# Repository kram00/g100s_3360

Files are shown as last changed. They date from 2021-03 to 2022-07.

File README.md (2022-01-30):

# g100s_3360

original code from https://gist.github.com/qsxcv/53c52e2bf6ed1f0b6c2a8a0d21219476 and https://www.overclock.net/threads/reverse-engineering-3366.1561041/post-28068670

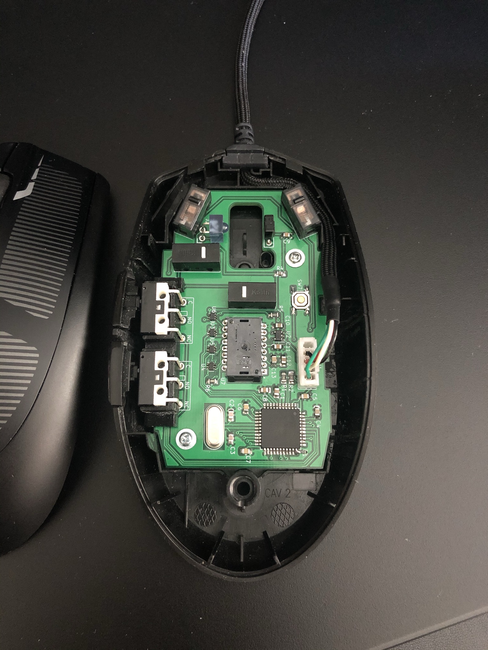
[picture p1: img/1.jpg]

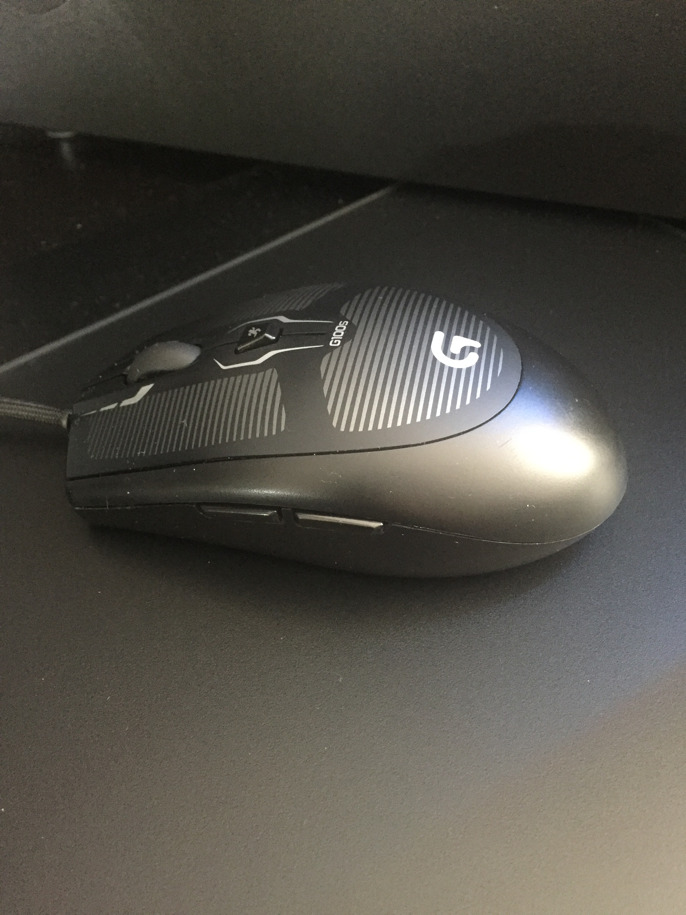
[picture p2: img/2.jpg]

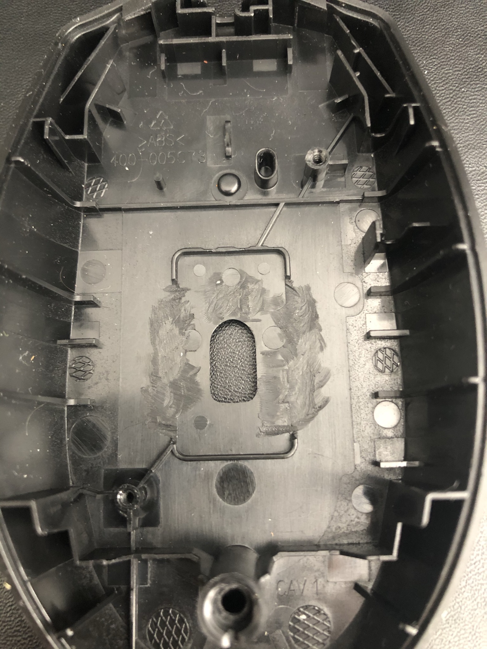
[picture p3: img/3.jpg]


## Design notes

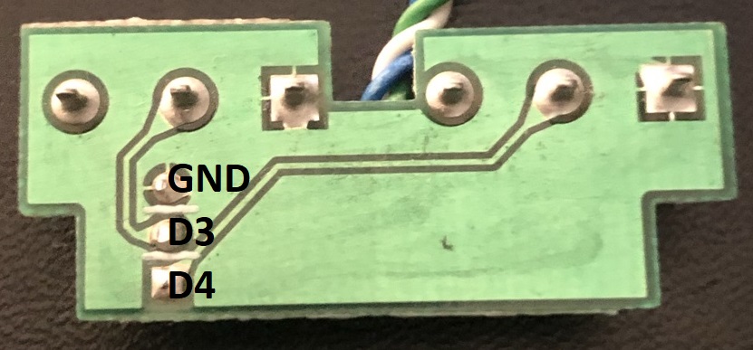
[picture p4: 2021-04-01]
img/sidebuttons.jpg

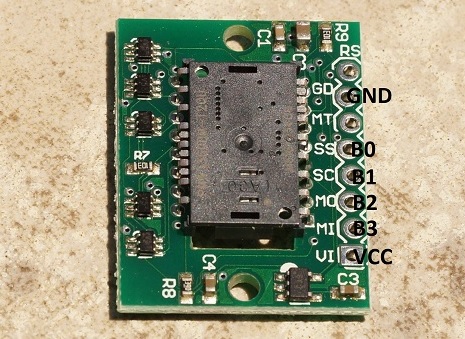
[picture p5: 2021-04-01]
img/3360_teensy.jpg

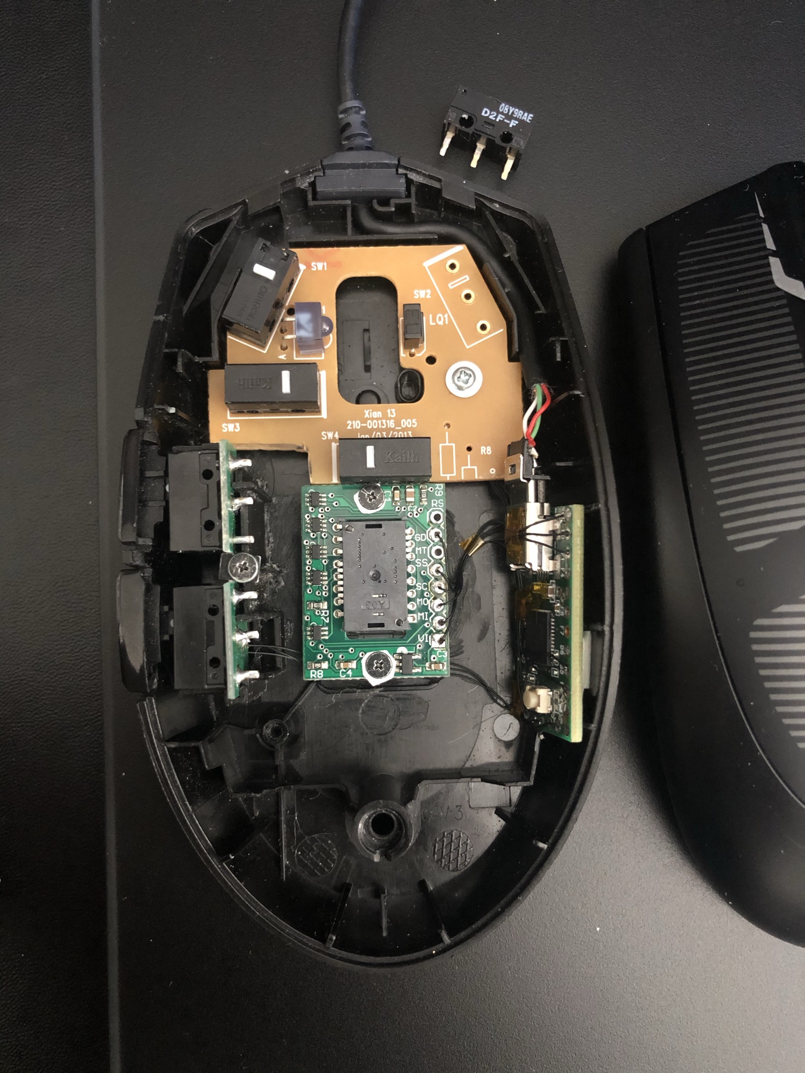
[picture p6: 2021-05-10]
img/g100s_3360_1.jpg

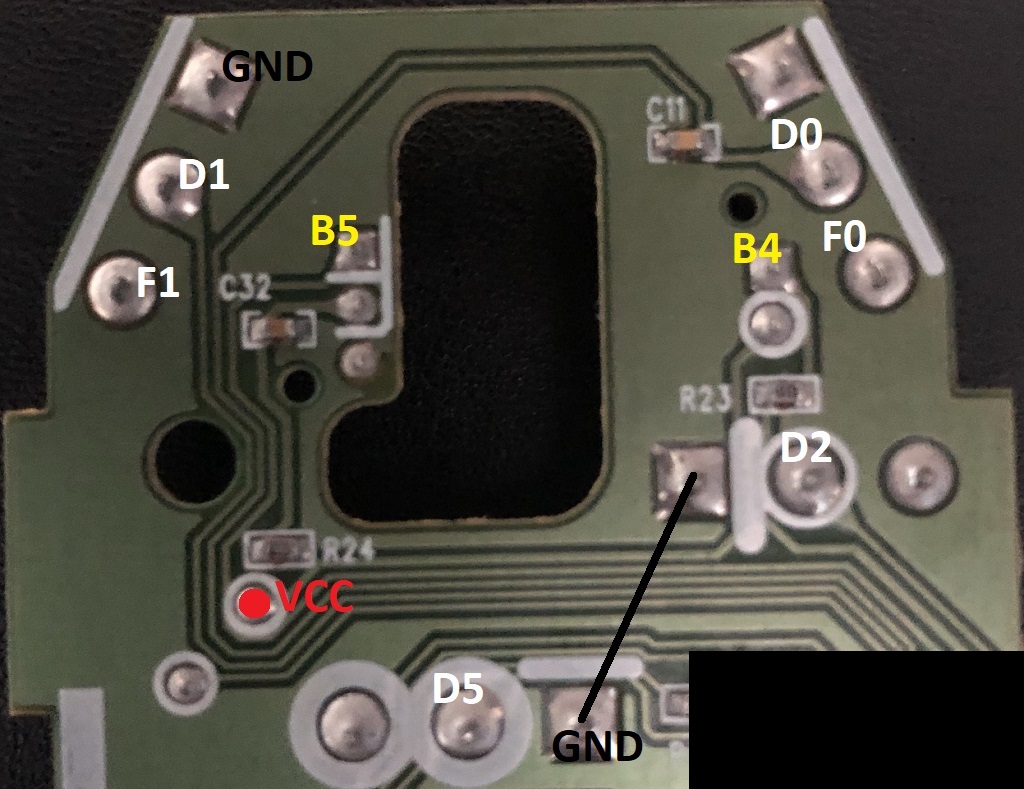
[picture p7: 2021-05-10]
img/buttons_scroll.jpg

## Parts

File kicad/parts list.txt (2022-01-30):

order on lcsc:

Samsung Electro-Mechanics CL21C220JBANNNC 22pF	2x	C1804
YAGEO CC0805KRX7R9BB104 100nF			5x	C49678
Samsung Electro-Mechanics CL21A475KAQNNNE 4.7uF	2x	C1779
Samsung Electro-Mechanics CL21B105KBFNNNE 1uF	4x	C28323
Uniroyal Elec 0805W8F1002T5E 10kΩ		1x	C17414
Uniroyal Elec 0805W8F220JT5E 22Ω		2x	C17561
Uniroyal Elec 0805W8F1500T5E 150Ω		1x	C17471
Uniroyal Elec 0805W8F100JT5E 10Ω		1x	C17415
Uniroyal Elec 0805W8F1001T5E 1kΩ		1x	C17513

Uniroyal Elec 0805W8F390JT5E 39Ω		1x	C17659
Microchip Tech ATMEGA32U4-AU C44854		1x	C44854
Texas Instruments SN74LVC1T45DCKR		4x	C9382
CITIZEN HC-49/U-S16000000ABJB			1x	C326538
								
-------------------------------------------------------------------------
not available on lcsc:

Texas Instruments TLV70019DDCR			1x	https://aliexpress.com/item/1005003054170479.html
PMW3360DM-T2QU + LM19-LSI			1x	https://aliexpress.com/item/32834829893.html
micro switch 4mmx4mmx1.5mm			1x	https://aliexpress.com/item/32915426986.html
ir led and detector				1x	recycle from g100s pcb or https://aliexpress.com/item/4000184464797.html
jst-ph 5pin					1x	recycle from g100s pcb or https://aliexpress.com/item/32400992588.html
								
-------------------------------------------------------------------------

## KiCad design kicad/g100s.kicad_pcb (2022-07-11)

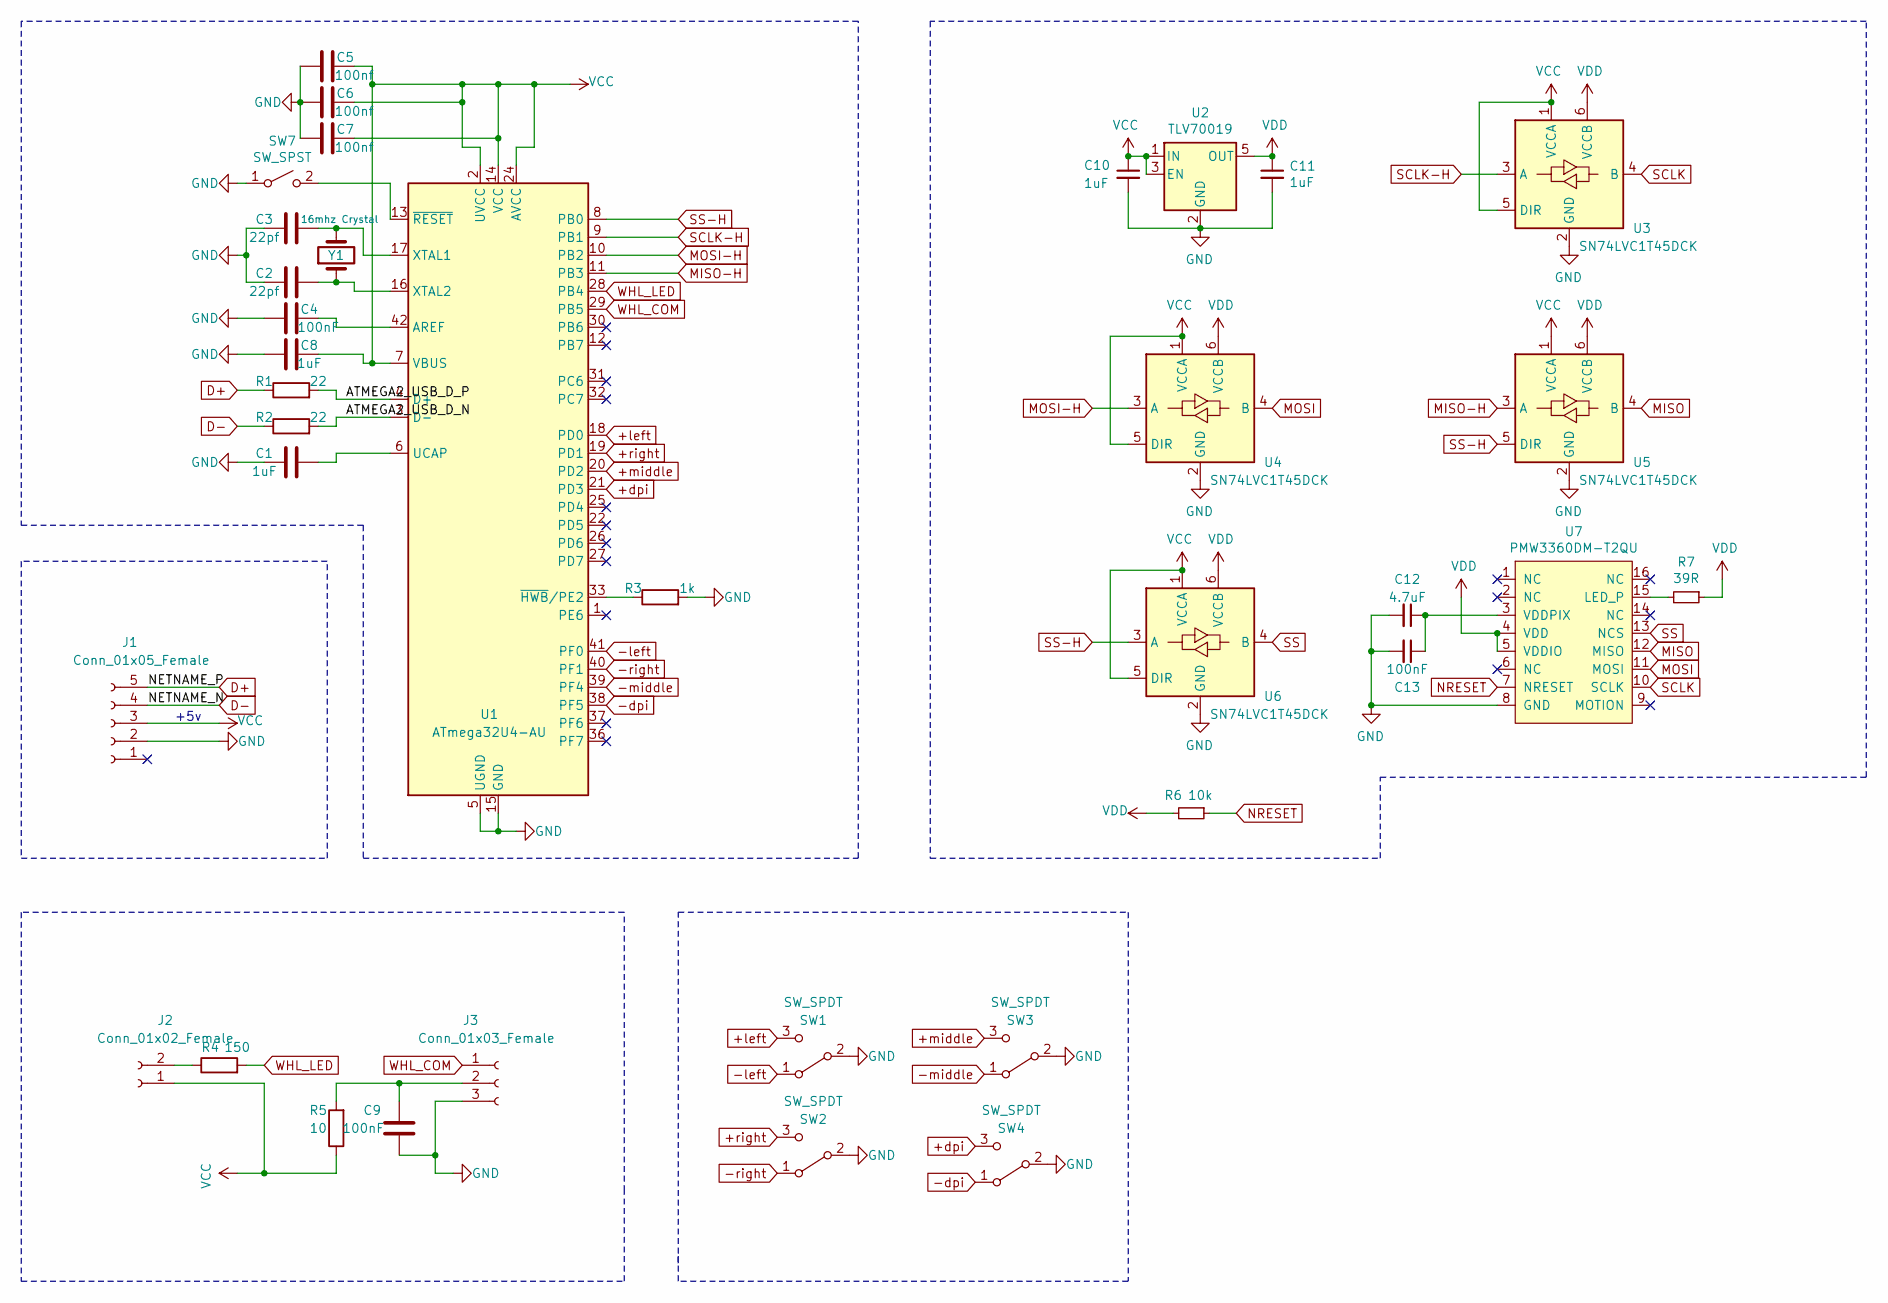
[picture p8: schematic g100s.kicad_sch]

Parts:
C1, C8, C10, C11: 1uF; C_0805_2012Metric_Pad1.18x1.45mm_HandSolder
C2, C3: 22pf; C_0805_2012Metric_Pad1.18x1.45mm_HandSolder
C4, C9, C13: 100nF; C_0805_2012Metric_Pad1.18x1.45mm_HandSolder
C5, C6, C7: 100nf; C_0805_2012Metric_Pad1.18x1.45mm_HandSolder
C12: 4.7uF; C_0805_2012Metric_Pad1.18x1.45mm_HandSolder
J1: Conn_01x05_Female; JST_PH_B5B-PH-K_1x05_P2.00mm_Vertical
J2: Conn_01x02_Female; PinSocket_1x02_P2.54mm_Vertical
J3: Conn_01x03_Female; PinSocket_1x03_P2.54mm_Vertical
R1, R2: 22; R_0805_2012Metric_Pad1.20x1.40mm_HandSolder
R3: 1k; R_0805_2012Metric_Pad1.20x1.40mm_HandSolder
R4: 150; R_0805_2012Metric_Pad1.20x1.40mm_HandSolder
R5: 10; R_0805_2012Metric_Pad1.20x1.40mm_HandSolder
R6: 10k; C_0805_2012Metric_Pad1.18x1.45mm_HandSolder
R7: 39R; C_0805_2012Metric_Pad1.18x1.45mm_HandSolder
SW1, SW2, SW3, SW4: SW_SPDT; Microswitch_SPDT_D2F
SW7: SW_SPST; SW_SPST_TL3342
U1: ATmega32U4-AU; TQFP-44_10x10mm_P0.8mm
U2: TLV70019; SOT-23-5
U3, U4, U5, U6: SN74LVC1T45DCK; SOT-363_SC-70-6
U7: PMW3360DM-T2QU
Y1: 16mhz Crystal; Crystal_HC49-U_Vertical

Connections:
+dpi: SW4.3 (C), U1.21 (PD3)
+left: SW1.3 (C), U1.18 (PD0)
+middle: SW3.3 (C), U1.20 (PD2)
+right: SW2.3 (C), U1.19 (PD1)
-dpi: SW4.1 (A), U1.38 (PF5)
-left: SW1.1 (A), U1.41 (PF0)
-middle: SW3.1 (A), U1.39 (PF4)
-right: SW2.1 (A), U1.40 (PF1)
/ATMEGA2_USB_D_N: R2.2, U1.3 (D-)
/ATMEGA2_USB_D_P: R1.2, U1.4 (D+)
D+: J1.5, R1.1
D-: J1.4, R2.1
GND: C1.1, C2.1, C3.1, C4.1, C5.1, C6.2, C7.2, C8.2, C9.1, C10.2, C11.2, C12.2, C13.2, J1.2, J3.3, R3.2, SW1.2 (B), SW2.2 (B), SW3.2 (B), SW4.2 (B), SW7.1 (A), U1.5 (UGND), U1.15 (GND), U1.23 (GND), U1.35 (GND), U1.43 (GND), U2.2 (GND), U3.2 (GND), U4.2 (GND), U5.2 (GND), U6.2 (GND), U7.8 (GND)
MISO: U5.4 (B), U7.12 (MISO)
MISO-H: U1.11 (PB3), U5.3 (A)
MOSI: U4.4 (B), U7.11 (MOSI)
MOSI-H: U1.10 (PB2), U4.3 (A)
NRESET: R6.1, U7.7 (NRESET)
unnamed: C1.2, U1.6 (UCAP)
unnamed: C2.2, U1.16 (XTAL2), Y1.1
unnamed: C3.2, U1.17 (XTAL1), Y1.2
unnamed: C4.2, U1.42 (AREF)
unnamed: C9.2, J3.2, R5.2
unnamed: C12.1, C13.1, U7.3 (VDDPIX)
unnamed: J2.2, R4.1
unnamed: R3.1, U1.33 (~HWB~/PE2)
unnamed: R7.2, U7.15 (LED_P)
unnamed: SW7.2 (B), U1.13 (~RESET)
SCLK: U3.4 (B), U7.10 (SCLK)
SCLK-H: U1.9 (PB1), U3.3 (A)
SS: U6.4 (B), U7.13 (NCS)
SS-H: U1.8 (PB0), U5.5 (DIR), U6.3 (A)
VCC: C5.2, C6.1, C7.1, C8.1, C10.1, J1.3, J2.1, R5.1, U1.2 (UVCC), U1.7 (VBUS), U1.14 (VCC), U1.24 (AVCC), U1.34 (VCC), U1.44 (AVCC), U2.1 (IN), U2.3 (EN), U3.1 (VCCA), U3.5 (DIR), U4.1 (VCCA), U4.5 (DIR), U5.1 (VCCA), U6.1 (VCCA), U6.5 (DIR)
VDD: C11.1, R6.2, R7.1, U2.5 (OUT), U3.6 (VCCB), U4.6 (VCCB), U5.6 (VCCB), U6.6 (VCCB), U7.4 (VDD), U7.5 (VDDIO)
WHL_COM: J3.1, U1.29 (PB5)
WHL_LED: R4.2, U1.28 (PB4)
no_connect_(J1-Pad1): J1.1
no_connect_(U1-Pad1): U1.1 (PE6)
no_connect_(U1-Pad12): U1.12 (PB7)
no_connect_(U1-Pad22): U1.22 (PD5)
no_connect_(U1-Pad25): U1.25 (PD4)
no_connect_(U1-Pad26): U1.26 (PD6)
no_connect_(U1-Pad27): U1.27 (PD7)
no_connect_(U1-Pad30): U1.30 (PB6)
no_connect_(U1-Pad31): U1.31 (PC6)
no_connect_(U1-Pad32): U1.32 (PC7)
no_connect_(U1-Pad36): U1.36 (PF7)
no_connect_(U1-Pad37): U1.37 (PF6)
no_connect_(U2-Pad4): U2.4 (NC)
no_connect_(U7-Pad1): U7.1 (NC)
no_connect_(U7-Pad2): U7.2 (NC)
no_connect_(U7-Pad6): U7.6 (NC)
no_connect_(U7-Pad9): U7.9 (MOTION)
no_connect_(U7-Pad14): U7.14 (NC)
no_connect_(U7-Pad16): U7.16 (NC)

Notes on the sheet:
+5v

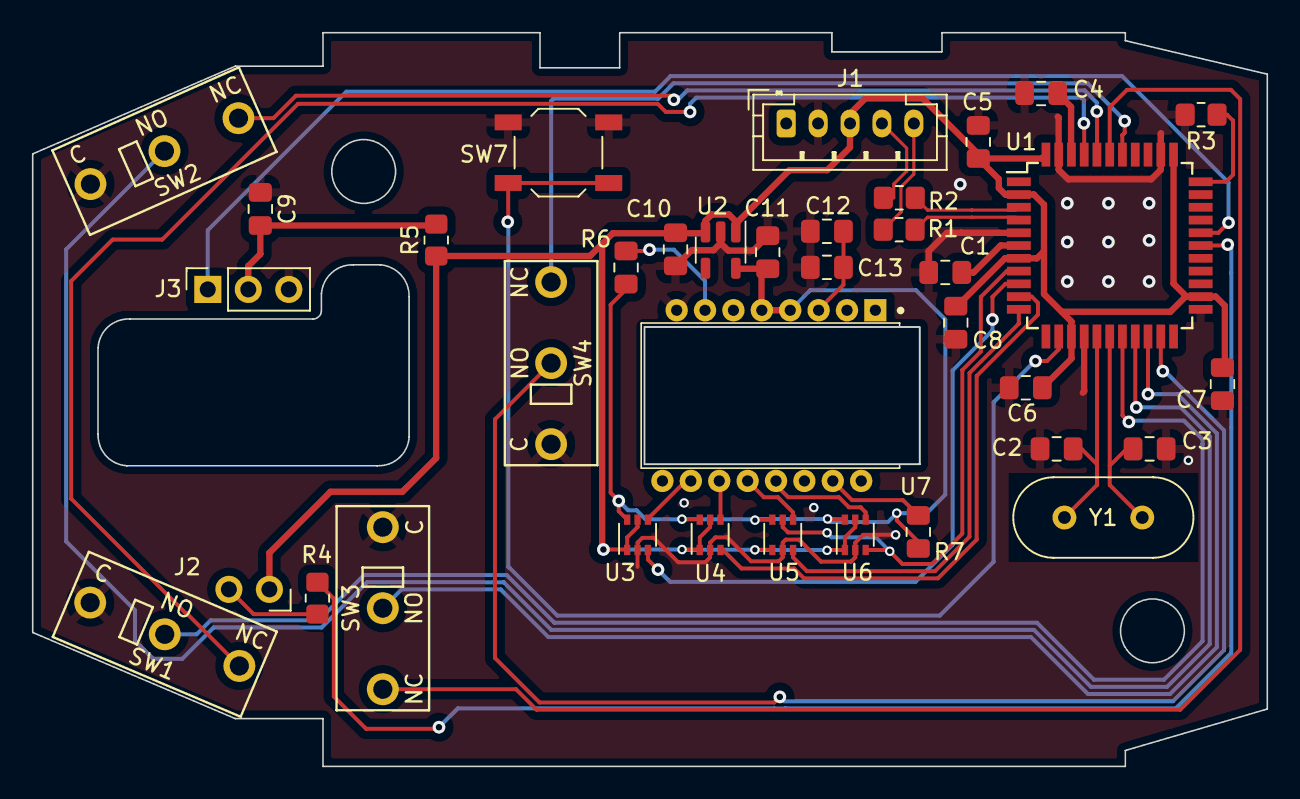
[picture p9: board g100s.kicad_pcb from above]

Board: 2 copper layers, 77.4 x 46.0 mm, 36 parts (0 on the bottom side), 36 nets.

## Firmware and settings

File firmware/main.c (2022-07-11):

#include <avr/io.h>
#include <avr/pgmspace.h>
#include <avr/interrupt.h>
#include <avr/eeprom.h>
#include "srom_3360_0x05.h"
#include "usb_mouse.h"

#define delay_us(t) __builtin_avr_delay_cycles((t) * (F_CPU/1000000))
#define delay_ms(t) __builtin_avr_delay_cycles((t) * (F_CPU/1000))

// button release latency. units are 125us, so 128 means 16ms.
#define DEBOUNCE_TIME 128

// how long before assuming wheel is in the center of a notch.
#define WHL_MAX_TIMEOUT 16000 // = 2 seconds

#define WHL_LED_ON (PORTB &= ~(1<<4))
#define WHL_LED_OFF (PORTB |= (1<<4))

#define PORT_SPI PORTB
#define DDR_SPI	DDRB

#define DD_SS	0 // aka NCS
#define DD_SCK	1
#define DD_MOSI	2
#define DD_MISO	3

#define SS_LOW	(PORT_SPI &= ~(1<<DD_SS))
#define SS_HIGH	(PORT_SPI |= (1<<DD_SS))

// use this instead of bitshifts or LSB/MSB macros.
union motion_data {
	int16_t all;
	struct { uint8_t lo, hi; };
};


static void pins_init(void)
{
	PORTD |= 0b00001111; // L, R, M, DPI pullup inputs on D0, D1, D2, D5. (active low)
	PORTF |= 0b00110011;

	EICRA = 0b01010101; // generate interrupt request on any edge of D0/D1/D2/D3
	EIMSK = 0; // but don't enable any actual interrupts
	EIFR = 0b00001111; // clear EIFR

	PORTB |= (1<<4);
	DDRB |= (1<<4); // B4 led (active low)
	DDRB &= ~(1<<5); // B5 detector input

	//DDRC |= (1<<2); PORTC |= (1<<2); // C2, 3360 NRESET high output
}


// spi functions
static void spi_init(void)
{
	DDR_SPI |= (1<<DD_MOSI) | (1<<DD_SCK) | (1<<DD_SS); // outputs
	// MISO pullup input is already done in hardware
	// enable spi, master mode, mode 3, clock rate = fck/4 = 2MHz
	SPCR = (1<<SPE) | (1<<MSTR) | (1<<CPOL) | (1<<CPHA);
}

static inline void spi_send(const uint8_t b)
{
	SPDR = b;
	while (!(SPSR & (1<<SPIF)));
}

static inline uint8_t spi_recv(void)
{
	spi_send(0x00);
	return SPDR;
}

static inline void spi_write(const uint8_t addr, const uint8_t data)
{
	spi_send(addr | 0x80);
	spi_send(data);
	delay_us(180); // maximum of t_SWW, t_SWR
}

static inline uint8_t spi_read(const uint8_t addr)
{
	spi_send(addr);
	delay_us(160); // t_SRAD
	uint8_t data = spi_recv();
	delay_us(20);
	return data;
}


static void pmw3360_init(const uint8_t dpi)
{
	SS_HIGH;
	delay_ms(3);

	// shutdown first
	SS_LOW;
	spi_write(0x3b, 0xb6);
	SS_HIGH;
	delay_ms(300);

	// drop and raise ncs to reset spi port
	SS_LOW;
	delay_us(40);
	SS_HIGH;
	delay_us(40);

	// power up reset
	SS_LOW;
	spi_write(0x3a, 0x5a);
	SS_HIGH;
	delay_ms(50);

	// read from 0x02 to 0x06
	SS_LOW;
	spi_read(0x02);
	spi_read(0x03);
	spi_read(0x04);
	spi_read(0x05);
	spi_read(0x06);

	spi_write(0x10, 0x00); // disable rest mode
	spi_write(0x22, 0x00); // ???

	// srom download
	spi_write(0x13, 0x1d);
	SS_HIGH;
	delay_ms(10);
	SS_LOW;
	spi_write(0x13, 0x18);

	const uint8_t *psrom = srom;
	spi_send(0x62 | 0x80);
	for (uint16_t i = 0; i < SROM_LENGTH; i++) {
		delay_us(16);
		spi_send(pgm_read_byte(psrom++));
	}
	delay_us(18);
	SS_HIGH;
	delay_us(200);

	// configuration/settings
	SS_LOW;
	spi_write(0x10, 0x00); // 0x00 disables rest mode use 0x20 for wireless
	spi_write(0x14, 0xff); // how long to wait before going to rest mode. 0xff is max (~10 seconds)
	spi_write(0x17, 0xff);
	spi_write(0x18, 0x00);
	spi_write(0x19, 0x00);
	spi_write(0x1b, 0x00);
	spi_write(0x1c, 0x00);

	// surface tuning default
	spi_write(0x2c, 0x0a);
	spi_write(0x2b, 0x10);
    // calibrated in logitech software with g pro (skypad)
	// spi_write(0x2c, 0x34);
	// spi_write(0x2b, 0xde);

	// configuration/settings
	spi_write(0x0f, dpi);
	spi_write(0x42, 0x00); // no angle snapping
	spi_write(0x63, 0x02); // 2mm lod
	SS_HIGH;
}

// reads the change from the wheel detector.
// see http://www.google.com/patents/US6552716
static inline int8_t whl_read(void)
{
	// read "B"
	PORTB |= (1<<5); // PORT before DDR to avoid outputting a falling edge
	DDRB |= (1<<5);
	delay_us(1); // not sure how long to delay. 1us seems sufficient
	PORTB &= ~(1<<5); // output a falling edge
	delay_us(1);
	DDRB &= ~(1<<5);
	delay_us(1);
	int8_t b = ((PINB & (1<<5)) != 0); // read the pin

	delay_us(1);

	// read "A"
	PORTB |= (1<<5);
	DDRB |= (1<<5);
	delay_us(1);
	PORTB &= ~(1<<5);
	delay_us(1);
	DDRB &= ~(1<<5);
	delay_us(1);
	int8_t a = ((PINB & (1<<5)) != 0);

	return (a - b);
	// toggle wheel led for ~25us after calling this function
}

uint8_t EEMEM stored_dpi_index = 1;
uint8_t btn_dbncd = 0x00;

int main(void)
{
	MCUCR |= _BV(JTD);
	MCUCR |= _BV(JTD); //disable Port F jtag by writing bit twice within 4 cycles.

	// set clock prescaler for 16MHz
	CLKPR = 0x80;
	CLKPR = 0x00;

	pins_init();

	// previous state to compare against for debouncing
	// uint8_t btn_prev = (~PIND) & 0x03; // read L+R
	uint8_t btn_prev = (~PIND) & 0b00001111; // read L, R, M, DPI
	// time (in 125us) button has been unpressed.
	// consider button to be released if this time exceeds DEBOUNCE_TIME.
	// uint8_t btn_time[4] = {0, 0, 0, 0};

	// if dpi button is pressed when plugging in, jump to bootloader
	// see https://www.pjrc.com/teensy/jump_to_bootloader.html
	delay_ms(50);
	if (!(PIND & (1<<5)))
		__asm__ volatile ("jmp 0x7000"); //atmel-dfu
		//__asm__ volatile ("jmp 0x7e00"); // teensy2.0 

	// wheel
	WHL_LED_ON; // initial pulse for first read
	delay_us(25);
	WHL_LED_OFF;
	// ticks are what the detector outputs.
	// for g100s's wheel/detector, 8 ticks = 1 scroll notch.
	// these two variables serve as accumulators, since the wheel is read
	// more frequently than usb data is transmitted
	int8_t whl_notches = 0;
	int8_t whl_ticks = 0;
	// if no wheel motion after this many cycles, reset whl_ticks.
	uint16_t whl_timeout = 0;

	union motion_data x_sum, y_sum; // total motion after last usb transmission
	spi_init();
	// dpi settings
	// uint8_t dpi_index = 1;
	static uint8_t dpi_index;
	uint8_t dpis[] = {3, 7, 15, 31, 63};
	dpi_index = eeprom_read_byte(&stored_dpi_index);
	pmw3360_init(dpis[dpi_index]);
	// begin burst mode
	SS_LOW;
	spi_write(0x50, 0x00);
	SS_HIGH;

	usb_init();
	while (!usb_configured());
	delay_ms(456); // arbitrary

	// set up timer0 to set OCF0A in TIFR0 every 125us
	TCCR0A = 0x02; // CTC
	TCCR0B = 0x02; // prescaler 1/8 = 1us period
	// OCR0A = 124; // = 125 - 1
	OCR0A = 249; // = 16000000 / (8 * 8000) - 1 .. for 16mhz use 249

	cli();
	for (uint8_t i = 0; ; i = (i + 1) % 8) {
	// synchronization to usb frames and 125us intervals
		// polling interrupt flags gives 5 clock cycles or so of
		// jitter. possible to eliminate by going into sleep
		// mode and waking up using interrupts, but whatever.
		if (i == 0) {
			// sync to usb frames (1ms)
			UDINT &= ~(1<<SOFI);
			while(!(UDINT & (1<<SOFI)));
			// reset prescaler phase, not really necessary
			GTCCR |= (1<<PSRSYNC);
			TCNT0 = 0;
		} else {
			// sync to 125us intervals using timer0
			while (!(TIFR0 & (1<<OCF0A)));
		}
		TIFR0 |= (1<<OCF0A); // 0CF0A is cleared by writing 1

	// check wheel timeout
		if (whl_timeout != 0) whl_timeout++;
		if (whl_timeout >= WHL_MAX_TIMEOUT) {
			whl_timeout = 0;
			whl_ticks = 0; // assume wheel is in center of a notch
		}


	// sensor stuff
		union motion_data x, y;
		SS_LOW;
		spi_send(0x50);

		// 3360 needs total of about 35us delay before reading registers
		// do wheel stuff here as a delay
		const int8_t _whl_ticks = whl_read(); // takes ~10us
		WHL_LED_ON;
		delay_us(25); // toggle wheel for next cycle's read
		WHL_LED_OFF;

		spi_send(0x00); // motion, not used
		spi_send(0x00); // observation, not used
		x.lo = spi_recv();
		x.hi = spi_recv();
		y.lo = spi_recv();
		y.hi = spi_recv();
		SS_HIGH;


	// wheel calculations
		whl_ticks += _whl_ticks;
		int8_t _whl_notches = 0;
		if (_whl_ticks != 0) {
			_whl_notches = whl_ticks / 5;
			// same as (whl_ticks > 4) - (whl_ticks < -4)
			whl_ticks -= _whl_notches * 8;
			whl_timeout = 1; //reset timeout
		}

	// button stuff
		//high = not pressed, low = pressed
		//PIND 0 EIFR 0: low, no edges -> is low
		//PIND 0 EIFR 1: low, edge -> is low
		//PIND 1 EIFR 0: high, no edges -> always high during last 125us
		//PIND 1 EIFR 1: high, edge -> low at some point in the last 125us
		// const uint8_t btn_raw = (~PIND) | EIFR;
		// EIFR = 0b00001111; // clear EIFR

		// button debouncing logic
		//          >input<           |        >output<
		//------------------------------------------------------
		// previous    | current      | unclicked  | current
		// dbncd state | actual state | time       | dbncd state
		//-------------+--------------+------------+------------
		//    btn_prev |      btn_raw | btn_time   |   btn_dbncd
		//-------------+--------------+------------+------------
		//           0 |            0 |         =0 |          =0
		//           0 |            1 |         =0 |          =1
		//           1 |            0 |         ++ | (time < DEBOUNCE_TIME)
		//           1 |            1 |         =0 |          =1
		// uint8_t btn_dbncd = 0x00;

		// // manual loop debouncing for every button
		/* #define DEBOUNCE(index) \
		if ((btn_prev & (1<<index)) && !(btn_raw & (1<<index))) { \
			btn_time[index]++; \
			if (btn_time[index] < DEBOUNCE_TIME) \
				btn_dbncd |= (1<<index); \
		} else { \
			btn_time[index] = 0; \
			btn_dbncd |= btn_raw & (1<<index); \
		}*/
		// DEBOUNCE(0); // L
		// DEBOUNCE(1); // R
		// DEBOUNCE(2); // M
		// DEBOUNCE(3); // RSB
		// DEBOUNCE(4); // FSB
		// DEBOUNCE(5); // DPI

		// #undef DEBOUNCE

	// hardware debouncing
		//+left click
		if (!(PIND & (1 << 0))) {
			btn_dbncd |= (1<<0);
		}
		//-left click
		if (!(PINF & (1 << 0))) {
			btn_dbncd &= ~(1<<0);
		}
		//+right click
		if (!(PIND & (1 << 1))) {
			btn_dbncd |= (1<<1);
		}
		//-right click
		if (!(PINF & (1 << 1))) {
			btn_dbncd &= ~(1<<1);
		}
		//+middle click
		if (!(PIND & (1 << 2))) {
			btn_dbncd |= (1<<2);
		}
		//-middle click
		if (!(PINF & (1 << 4))) {
			btn_dbncd &= ~(1<<2);
		}
		//+dpi click
		if (!(PIND & (1 << 3))) {
			btn_dbncd |= (1<<3);
		}
		//-dpi click
		if (!(PINF & (1 << 5))) {
			btn_dbncd &= ~(1<<3);
		}

	// usb
		// first make sure it's configured
		sei();
		while (!usb_configured());
		cli();
		// this stuff is very intricate and confusing
		// i'm fairly certain all of it is correct.
		// there's nothing to do if nothing's changed in this 125us cycle
		if ((btn_dbncd != btn_prev) || x.all || y.all || _whl_notches) {
			UENUM = MOUSE_ENDPOINT;
			if (UESTA0X & (1<<NBUSYBK0)) { // untransmitted data still in bank
				UEINTX |= (1<<RXOUTI); // kill bank; RXOUTI == KILLBK
				while (UEINTX & (1<<RXOUTI));
			} else {
				// transmission's finished, or the data that should be in the
				// bank is exactly the same as what was previously transmitted
				// so that there was nothing worth transmitting before.
				x_sum.all = 0;
				y_sum.all = 0;
				whl_notches = 0;
			}
			x_sum.all += x.all;
			y_sum.all += y.all;
			whl_notches += _whl_notches;
			// only load bank with data if there's something worth transmitting
			if ((btn_dbncd != btn_prev) || x_sum.all || y_sum.all || whl_notches) {
				UEDATX = btn_dbncd;
				UEDATX = x_sum.lo;
				UEDATX = x_sum.hi;
				UEDATX = y_sum.lo;
				UEDATX = y_sum.hi;
				UEDATX = whl_notches; // wheel scrolls
				UEINTX = 0x3a;
				// btn_prev = btn_dbncd;
			}
		}
		// when dpi and right button is pressed cycle dpi and save changes in eeprom
		// if ((btn_dbncd & 0x20) && !(btn_prev & 0x20)) {
		if (!(PIND & (1<<1)) && !(PIND & (1<<5))) {
			delay_ms(500);
			dpi_index = (dpi_index + 1) %
					(sizeof(dpis)/sizeof(dpis[0]));
			SS_LOW; delay_us(1);
			spi_write(0x0f, dpis[dpi_index]);
			SS_HIGH;
			eeprom_write_byte(&stored_dpi_index, dpi_index);
		}

		btn_prev = btn_dbncd;
	}
}

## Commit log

2021-06-12 made a custom pcb
    [g100s-B_Cu.gbl, g100s-B_Mask.gbs, g100s-B_Paste.gbp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]
2021-06-21 update stl
    [hook.stl]
2021-07-14 update kicad files
    [g100s.kicad_pcb, g100s.kicad_sch]
2022-07-11 remove sidebuttons
    [g100s-B_Cu.gbl, g100s-B_Mask.gbs, g100s-B_Paste.gbp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]
